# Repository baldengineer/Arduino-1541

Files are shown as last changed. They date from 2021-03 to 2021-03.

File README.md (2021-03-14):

# Arduino-1541
Interact with a Commodore 1541 from an Arduino

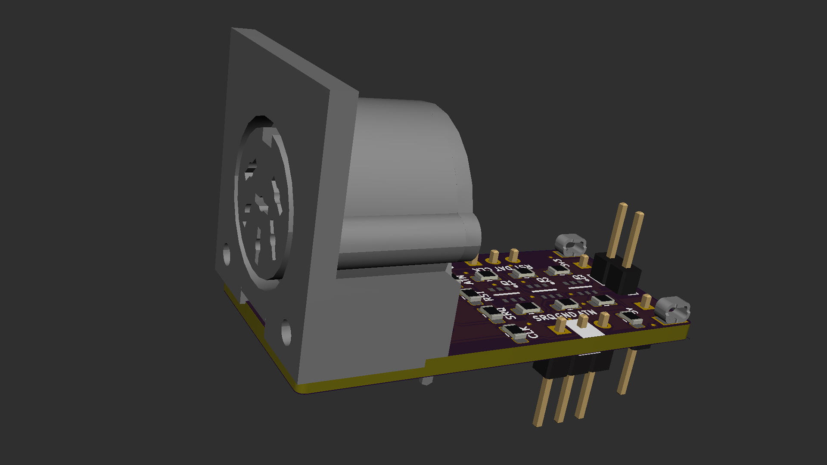
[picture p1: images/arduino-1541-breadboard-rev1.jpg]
1541 breadboard adapter for arduino


## Streaming notes
This project was created as a part of a [Bald Engineer Live Stream](https://twitch.tv/baldengineer). For stream-by-stream notes, [check out this repo](https://bald.ee/60-notes).

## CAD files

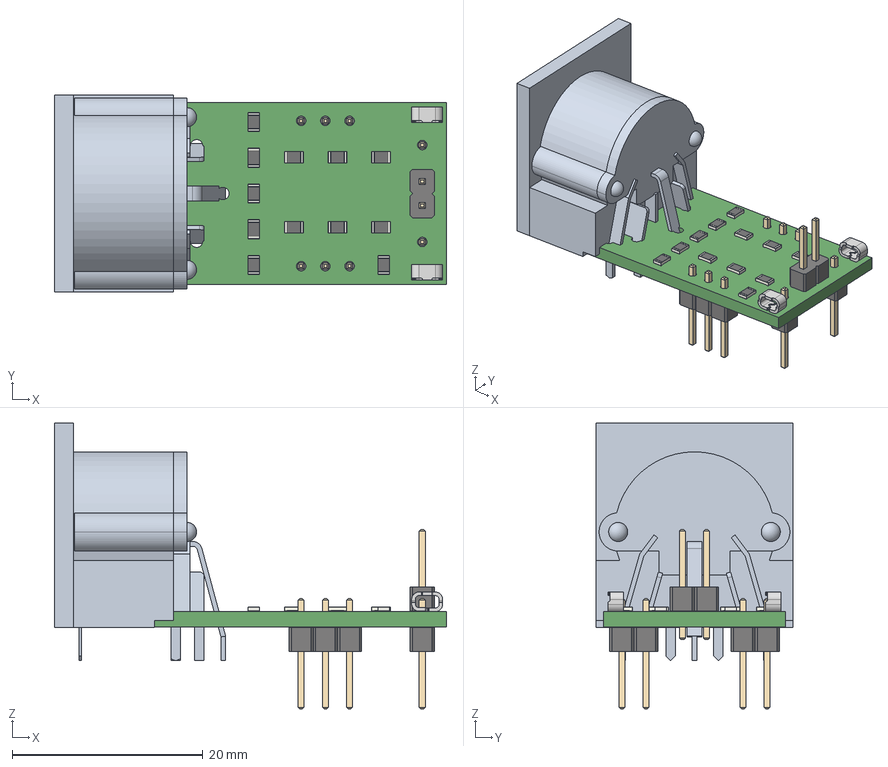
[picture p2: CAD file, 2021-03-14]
kicad/din-6-breadboard/din-6-breadboard.step
41.1 x 20.7 x 29.9 mm

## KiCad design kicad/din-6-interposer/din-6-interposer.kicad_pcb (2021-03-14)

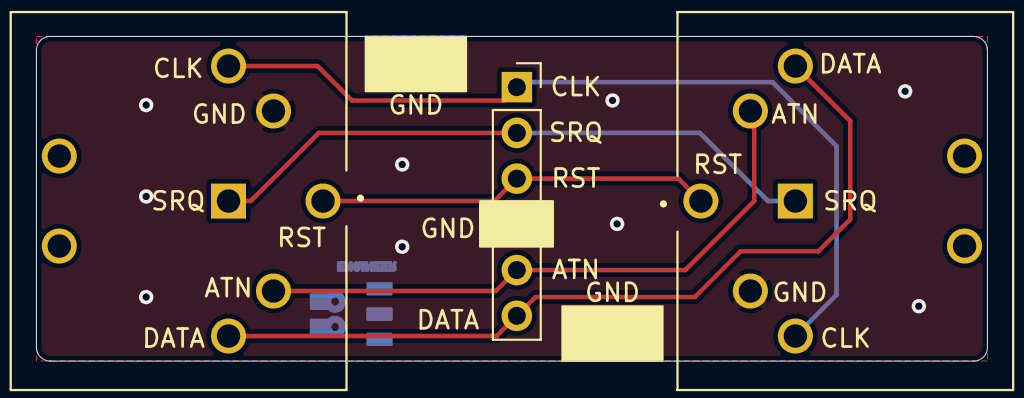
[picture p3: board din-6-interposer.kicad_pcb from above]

Board: 2 copper layers, 52.8 x 18.0 mm, 6 parts (1 on the bottom side), 6 nets.

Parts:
J1: LA; PinSocket_1x06_P2.54mm_Vertical
J2: IN; CUI_SDF-60J
J3: OUT; CUI_SDF-60J
TP1, TP2: GND; Harwin-S1751-46-Test-Point
svg2mod: G***; BE5v2

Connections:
/ATN: J1.5, J2.3, J3.3
/CLK: J1.1, J2.4, J3.4
/DATA: J1.6, J2.5, J3.5
/RESET: J1.3, J2.6, J3.6
/SRQ: J1.2, J2.1, J3.1
GND: J1.4, J2.2, J3.2, TP1.1, TP2.1

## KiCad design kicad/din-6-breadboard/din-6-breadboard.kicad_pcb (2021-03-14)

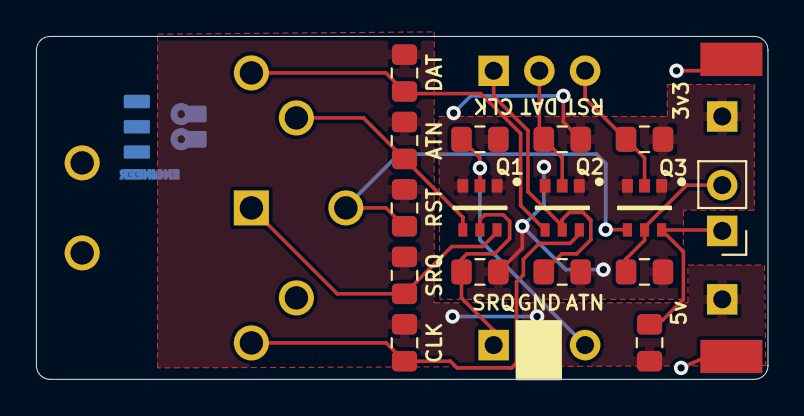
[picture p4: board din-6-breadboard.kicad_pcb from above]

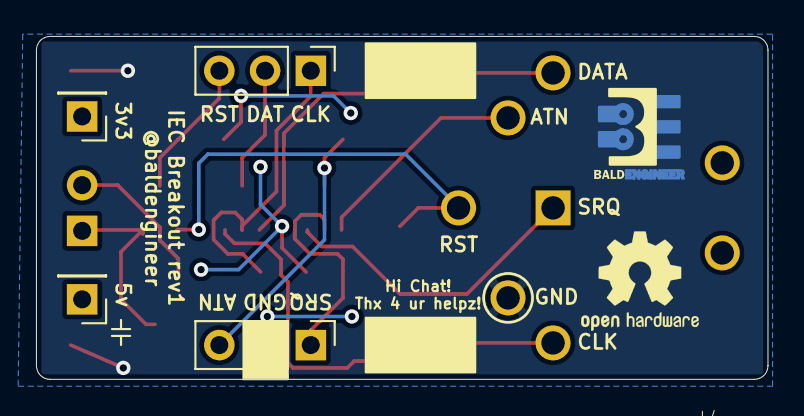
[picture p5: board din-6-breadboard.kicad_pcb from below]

Board: 2 copper layers, 40.6 x 19.0 mm, 24 parts (6 on the bottom side), 15 nets.

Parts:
J1, J2: Conn_01x03; PinHeader_1x03_P2.54mm_Vertical
J3: Conn_01x02; PinHeader_1x02_P2.54mm_Vertical
J4: IN; CUI_SDF-60J
J5: 3v3; PinHeader_1x01_P2.54mm_Vertical
J6: 5v; PinHeader_1x01_P2.54mm_Vertical
Q1, Q2, Q3: FDC6301N; ON_Semi-419AG-01-0-0-0
R1, R2, R3, R4, R5, R6, R7, R8, R9, R10, R11, R12: 4k7; R_0805_2012Metric_Pad1.15x1.40mm_HandSolder
TP1, TP2: GND; Harwin-S1751-46-Test-Point
svg2mod: G***; BE5v2

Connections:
+3V3: J5.1, Q1.1, Q1.3, Q2.1, Q2.3, Q3.1, Q3.3, R1.2, R3.2, R5.2, R7.2, R9.2, R11.2
+5V: J6.1, R2.2, R4.2, R6.2, R8.2, R10.2, R12.2
/ATN3: J1.3, Q1.2, R3.1
/ATN5: J4.3, Q1.4, R4.1
/CLK3: J2.1, Q2.5, R5.1
/CLK5: J4.4, Q2.6, R6.1
/DATA3: J2.2, Q2.2, R7.1
/DATA5: J4.5, Q2.4, R8.1
/RESET3: J2.3, Q3.2, R9.1
/RESET5: J4.6, Q3.4, R10.1
/SRQ3: J1.1, Q1.5, R1.1
/SRQ5: J4.1, Q1.6, R2.1
/Spare_Aux_H: J3.1, Q3.6, R12.1
/Spare_Aux_L: J3.2, Q3.5, R11.1
GND: J1.2, J4.2, TP1.1, TP2.1

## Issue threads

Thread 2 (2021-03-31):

DIN6 Connector is wrong in REV1

baldengineer, 2021-03-31:
Rev1 of the interposer and breakout boards have an issue with the DIN6 pinout. The KiCad footprint's pin numbering did not match the physical connector.

The Interposer only works in one direction.

The breadboard adapter probably works okay, but the pinouts are wrong.

`
PCB   C64
---------
DAT = DAT
ATN = CLK
SRQ = ATN
`

Need to fix in revision two.

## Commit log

2021-03-14 pre-flood 3v and 5v
    [din-6-breadboard.kicad_pcb, din-6-breadboard.sch]
2021-03-14 breakout r1 ready for fab
    [din-6-breadboard.kicad_pcb, din-6-breadboard.sch, din-6-breadboard.step]
2021-03-14 interpose rev1 finish
    [din-6-interposer.kicad_pcb, din-6-interposer.sch]
